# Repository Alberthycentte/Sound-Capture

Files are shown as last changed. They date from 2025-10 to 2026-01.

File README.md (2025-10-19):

# Sound Capture Device - User Manual By Albert Hycentte

## 📖 Table of Contents
1. [Introduction](#introduction)
2. [Hardware Overview](#hardware-overview)
3. [Getting Started](#getting-started)
4. [Operating Instructions](#operating-instructions)
5. [LED Status Indicators](#led-status-indicators)
6. [Technical Specifications](#technical-specifications)
7. [Firmware Upload Guide](#firmware-upload-guide)
8. [Troubleshooting](#troubleshooting)
9. [File Management](#file-management)
10. [Maintenance & Care](#maintenance--care)
11. [Advanced Configuration](#advanced-configuration)
12. [Safety Information](#safety-information)

---

## 🎤 Introduction

Welcome to the **Sound Capture Device**! This portable audio recorder allows you to:
- Record high-quality audio with a professional MEMS microphone
- Store recordings as standard WAV files on an SD card
- Play back recordings through a built-in amplifier and speaker
- Operate on battery power or USB for extended recording sessions

This device is perfect for voice memos, field recordings, interviews, lectures, music practice, or any situation where you need reliable audio capture.

---

## 🔧 Hardware Overview

### Main Components

| Component | Description | Location |
|---|---|---|
| **ESP32-S3** | Main processor | Center of PCB |
| **INMP441** | MEMS microphone | Bottom right of board |
| **MAX98357A** | Class D audio amplifier | Near speaker connector |
| **SD Card Slot** | Storage for recordings | Bottom left edge |
| **USB-C Port** | Power & programming | Top-left corner |
| **Battery Connector** | LiPo battery input | Left side |
| **Speaker Connector** | 4-8Ω speaker output | Left side |

### User Interface

#### Buttons (Bottom Edge)
```
[START]  [STOP]  [PLAY]  [BOOT]  [EN]
   │       │       │       │      │
   │       │       │       │      └─── Reset button
   │       │       │       └────────── Programming mode
   │       │       └────────────────── Play last recording
   │       └────────────────────────── Stop recording/playback
   └────────────────────────────────── Start recording
```

#### Status LED
- Located near buttons
- Provides visual feedback for all operations
- See [LED Status Indicators](#led-status-indicators) for details

---

## 🚀 Getting Started

### What You Need

**Essential:**
- ✅ Sound Capture Device
- ✅ MicroSD card (4GB - 32GB, FAT32 formatted)
- ✅ USB-C cable (for charging/programming)
- ✅ 4Ω or 8Ω speaker (2-3W rating)

**Optional:**
- 🔋 3.7V LiPo battery (1000-2000mAh recommended)
- 💻 Computer (for firmware updates)

### Initial Setup

#### Step 1: Insert SD Card
1. Power off the device
2. Insert microSD card into slot (gold contacts facing down)
3. Push until it clicks into place
4. **Important:** Card must be formatted as FAT32

#### Step 2: Connect Speaker
1. Locate the 2-pin speaker connector (SPK)
2. Connect speaker wires 
3. Use 4Ω or 8Ω speaker rated for 2-3W

#### Step 3: Power Connection

**Option A: USB Power**
- Connect USB-C cable to device
- Connect other end to USB power adapter or computer
- LED should blink twice on startup

**Option B: Battery Power**
- Connect 3.7V LiPo battery to J2 connector
- Observe polarity: RED (+), BLACK (-)
- Battery charges automatically when USB connected

#### Step 4: First Power-On
1. Connect power source
2. Wait for LED indicators:
   - 2 blinks = System starting
   - 3 blinks = Ready to use
3. Device is now ready for recording!

---

## 🎵 Operating Instructions

### Recording Audio

**Basic Recording:**
1. **Press START button** once
   - LED turns ON (solid)
   - Recording begins immediately
2. Speak or capture audio (max 60 seconds)
3. **Press STOP button** to finish
   - LED blinks 2 times
   - File saved to SD card

**Recording Tips:**
- Speak clearly at normal volume
- Avoid covering microphone hole
- Recording stops automatically after 60 seconds
- Each recording creates a new numbered file (`rec_1.wav`, `rec_2.wav`, etc.)

### Playing Back Audio

**Playing Last Recording:**
1. **Press PLAY button** once
   - LED blinks slowly (500ms intervals)
   - Last recorded file plays automatically
2. Audio plays through connected speaker
3. Playback stops automatically at end
   - Or press STOP button to interrupt

**Volume:**
- Volume is set by hardware (12dB gain)
- To adjust, modify GAIN_SLOT resistor (see Advanced Configuration)

### Stopping Operations

**Stop Recording or Playback:**
- **Press STOP button** at any time
- Current operation terminates immediately
- LED blinks to confirm stop
- File is saved (if recording) before stopping

---

## 💡 LED Status Indicators

Understanding the status LED helps you know what the device is doing:

| LED Pattern | Meaning | Action |
|---|---|---|
| **2 blinks on power-up** | System initializing | Wait 2-3 seconds |
| **3 quick blinks** | System ready | Device ready to use |
| **Solid ON** | Recording in progress | Recording audio |
| **Slow blink (500ms)** | Playing audio | Playback in progress |
| **2 blinks after stop** | File saved successfully | Recording complete |
| **3 blinks (play press)** | No recordings found | Record something first |
| **5 rapid blinks** | Error detected | Check SD card or connections |
| **Continuous rapid blinks** | Critical error | Check troubleshooting section |

---

## 📊 Technical Specifications

### Audio Performance
| Parameter | Specification |
|---|---|
| **Sample Rate** | 16 kHz (voice optimized) |
| **Bit Depth** | 16-bit |
| **Channels** | Mono |
| **Format** | WAV (PCM uncompressed) |
| **Frequency Response** | 50 Hz - 8 kHz |
| **Microphone SNR** | 61 dB |
| **Amplifier Output** | 3.2W @ 4Ω, 1.4W @ 8Ω |
| **THD+N** | < 1% @ 1kHz |

### Recording Capacity
| SD Card Size | Recording Time @ 16kHz |
|---|---|
| 4 GB | ~74 hours |
| 8 GB | ~148 hours |
| 16 GB | ~296 hours |
| 32 GB | ~592 hours |

**File Size:** Approximately 1.8 MB per minute of recording

### Power Specifications
| Mode | Current Draw | Battery Life (1000mAh) |
|---|---|---|
| **Idle** | 50 mA | ~20 hours |
| **Recording** | 150 mA | ~6.5 hours |
| **Playback (medium volume)** | 250 mA | ~4 hours |
| **Charging** | Up to 1000 mA | ~1.5 hours |

### Physical Specifications
- **Supply Voltage:** 5V USB or 3.7V LiPo battery
- **Operating Temperature:** 0°C to 50°C
- **Storage Temperature:** -20°C to 60°C
- **Humidity:** 10% to 85% non-condensing

---

## 💻 Firmware Upload Guide

### Prerequisites

**Software Requirements:**
- Visual Studio Code (recommended) or Arduino IDE
- PlatformIO extension (for VS Code)
- USB-C cable
- Computer (Windows/Mac/Linux)

### Installation Steps

#### 1. Install PlatformIO
```bash
# For VS Code users:
1. Open VS Code
2. Go to Extensions (Ctrl+Shift+X)
3. Search "PlatformIO IDE"
4. Click Install

# For command line:
pip install platformio
```

#### 2. Prepare Project
```
Create folder structure:
sound_capture/
├── platformio.ini
├── src/
│   └── main.cpp
└── include/
```

#### 3. Configure platformio.ini
```ini
[env:esp32-s3-devkitc-1]
platform = espressif32
board = esp32-s3-devkitc-1
framework = arduino
upload_speed = 921600
monitor_speed = 115200
```

#### 4. Upload Firmware

**Method A: Using VS Code**
1. Connect USB-C cable to device
2. Hold **BOOT button** (GPIO0)
3. Press and release **EN button**
4. Release **BOOT button**
5. Click "Upload" in PlatformIO toolbar
6. Wait for "SUCCESS" message

**Method B: Command Line**
```bash
cd sound_capture
pio run --target upload
```

#### 5. Verify Upload
```bash
# Open serial monitor
pio device monitor

# You should see:
=== Sound Capture Device ===
Initializing...
System ready!
```

### Firmware Updates
To update firmware in the future:
1. Download new firmware release
2. Follow upload steps above
3. Your recordings on SD card are preserved
4. Settings may need reconfiguration

---

## 🔧 Troubleshooting

### SD Card Issues

**Problem: "SD card mount failed"**
- ✅ Check card is fully inserted
- ✅ Format card as FAT32 (not exFAT or NTFS)
- ✅ Try a different SD card
- ✅ Clean SD card contacts
- ✅ Use card 32GB or smaller

**Problem: "Failed to create file"**
- ✅ Check SD card is not write-protected
- ✅ Ensure card has free space
- ✅ Verify card is formatted correctly
- ✅ Try creating `/recordings` folder manually

### Audio Issues

**Problem: No sound when recording**
- ✅ Check microphone is not blocked
- ✅ Speak louder or move closer (6-12 inches)
- ✅ Verify INMP441 power (3.3V)
- ✅ Check GPIO36, 37, 38 connections
- ✅ Test with different recording

**Problem: No sound during playback**
- ✅ Verify speaker is connected
- ✅ Check speaker impedance (4-8Ω)
- ✅ Ensure volume is adequate (hardware gain)
- ✅ Test speaker with another device
- ✅ Check GPIO3 is enabling amplifier

**Problem: Distorted or garbled audio**
- ✅ Reduce volume (change GAIN_SLOT)
- ✅ Don't speak too close to microphone
- ✅ Check for loose connections
- ✅ Verify sample rate (16kHz default)
- ✅ Try re-recording

### Power Issues

**Problem: Device won't turn on**
- ✅ Check USB cable is connected
- ✅ Verify battery is charged
- ✅ Try different USB power source
- ✅ Check battery polarity
- ✅ Press EN button to reset

**Problem: Battery not charging**
- ✅ Ensure USB is connected
- ✅ Check charge LED (D5) is ON
- ✅ Verify battery polarity
- ✅ Battery may be fully charged
- ✅ Wait 1-2 hours for full charge

### Button Issues

**Problem: Buttons not responding**
- ✅ Press firmly and release
- ✅ Wait 200ms between presses (debounce)
- ✅ Check device is in IDLE state
- ✅ Reset device (EN button)
- ✅ Verify GPIO connections

### Error LED Patterns

**5 rapid blinks:**
1. Check SD card is inserted
2. Verify card is formatted FAT32
3. Check all connections
4. Re-upload firmware
5. Check serial monitor for details

---

## 📁 File Management

### File Structure
```
SD Card Root/
└── recordings/
    ├── rec_1.wav
    ├── rec_2.wav
    ├── rec_3.wav
    └── ...
```

### Accessing Recordings

**On Computer:**
1. Remove SD card from device
2. Insert into computer SD card reader
3. Navigate to `recordings` folder
4. Copy WAV files to computer
5. Files can be played with any media player

**Supported Players:**
- Windows Media Player
- VLC Media Player
- QuickTime (Mac)
- Any WAV-compatible software

### File Naming
- Files automatically numbered: `rec_1.wav`, `rec_2.wav`, etc.
- Device remembers last number used
- Deleting files resets numbering to highest existing number + 1

### Storage Management

**Checking Free Space:**
- Serial monitor shows card size on startup
- Monitor: "SD Card Size: XXXXMB"

**Deleting Old Recordings:**
1. Remove SD card
2. Connect to computer
3. Delete unwanted files from `/recordings/` folder
4. Re-insert card into device
5. Next recording continues numbering

**Backup Recommendations:**
- Copy recordings to computer regularly
- Keep SD card backups
- Card can be reformatted if needed (loses all data)

---

## 🛠️ Maintenance & Care

### Daily Use
- Keep device clean and dry
- Avoid extreme temperatures
- Don't cover microphone hole
- Store in protective case when not in use

### SD Card Care
- Don't remove card while recording
- Keep contacts clean
- Avoid static discharge
- Replace every 2-3 years for reliability

### Battery Maintenance
- Charge fully before first use
- Don't fully discharge (keep above 20%)
- Charge at room temperature
- Replace if runtime significantly decreases
- Store at 40-60% charge if unused for months

### Speaker Care
- Don't exceed 3W rating
- Avoid water exposure
- Check connections periodically
- Replace if sound becomes distorted

### Cleaning
- Use dry, soft cloth for exterior
- Don't use liquids near electronics
- Compressed air can clean microphone hole
- Clean SD card slot with dry brush

### Firmware Updates
- Check for updates periodically
- Updates may add features or fix bugs
- Follow upload guide for updates
- Backup recordings before updating

---

## ⚙️ Advanced Configuration

### Changing Audio Quality

**Location:** Line 51-54 in `main.cpp`

```cpp
// Voice recording (default)
#define SAMPLE_RATE    16000
#define SAMPLE_BITS    16
#define I2S_CHANNELS   1

// Music quality
#define SAMPLE_RATE    44100  // CD quality
#define SAMPLE_BITS    16
#define I2S_CHANNELS   1      // or 2 for stereo

// Phone quality (smaller files)
#define SAMPLE_RATE    8000
```

**Effect on file size:**
- 8 kHz: ~0.9 MB/min
- 16 kHz: ~1.8 MB/min
- 44.1 kHz: ~5 MB/min

### Adjusting Recording Time

**Location:** Line 54 in `main.cpp`

```cpp
#define RECORD_TIME_MS  60000  // 60 seconds

// Change to:
#define RECORD_TIME_MS  120000  // 2 minutes
#define RECORD_TIME_MS  300000  // 5 minutes
```

### Volume Adjustment (Hardware)

**Current Configuration:**
- GAIN_SLOT connected to VSYST (5V) via 0Ω resistor (R23)
- This provides 12dB gain

**To Change Volume:**

| R23 Connection | Gain | Volume |
|---|---|---|
| GND | 9dB | Quieter |
| +3.3V | 12dB | Normal (current) |
| 100K to GND | 15dB | Louder |
| Open (DNP) | 18dB | Maximum |

**To modify:** Remove R23 and connect to desired voltage

### Custom File Naming

**Location:** Line 382 in `main.cpp`

```cpp
// Default naming
currentFileName = "/recordings/rec_" + String(recordingNumber) + ".wav";

// Custom naming examples:
currentFileName = "/recordings/audio_" + String(recordingNumber) + ".wav";
currentFileName = "/recordings/memo_" + String(millis()) + ".wav";
```

### Buffer Size Optimization

**Location:** Line 57 in `main.cpp`

```cpp
#define DMA_BUF_LEN    512  // Default

// For better quality, increase:
#define DMA_BUF_LEN    1024

// For lower latency, decrease:
#define DMA_BUF_LEN    256
```

**Note:** Larger buffers = smoother recording but more memory usage

---

## ⚠️ Safety Information

### Electrical Safety
- ⚡ Use only 5V USB power supply
- ⚡ Battery: 3.7V LiPo only (1000-2000mAh)
- ⚡ Observe battery polarity
- ⚡ Don't short-circuit battery terminals
- ⚡ Disconnect power during repairs

### Battery Safety
- 🔋 Use quality LiPo batteries with protection circuit
- 🔋 Don't puncture, crush, or disassemble battery
- 🔋 Keep away from heat/fire
- 🔋 Don't charge unattended
- 🔋 Dispose properly at recycling center

### Operating Precautions
- 💧 Not waterproof - avoid moisture
- 🌡️ Don't use in extreme temperatures
- 👂 Avoid excessive speaker volume near ears
- 🎤 Microphone not for medical/safety-critical use
- 📱 May interfere with sensitive equipment

### Environmental
- ♻️ Dispose of electronics responsibly
- ♻️ Recycle batteries at designated facilities
- ♻️ Keep away from children and pets
- ♻️ Follow local e-waste regulations

---

## 📞 Support & Resources

### Getting Help
1. Check this manual first
2. Review troubleshooting section
3. Check serial monitor for error messages
4. Verify all connections
5. Try known-good components (SD card, battery, etc.)

### Technical Support
- **Serial Monitor:** Connect USB and run `pio device monitor`
- **Debug Output:** Detailed startup and operation info
- **Error Messages:** Specific problem indicators

### Additional Resources
- **ESP32-S3 Datasheet:** Technical specifications
- **INMP441 Datasheet:** Microphone specifications
- **MAX98357A Datasheet:** Amplifier details
- **PlatformIO Documentation:** Development environment

---

## 📄 Specifications Summary

| Category | Details |
|---|---|
| **Processor** | ESP32-S3 Dual-core @ 240MHz |
| **Memory** | 512KB RAM, 16MB Flash |
| **Microphone** | INMP441 MEMS I2S |
| **Amplifier** | MAX98357A Class D, 3.2W |
| **Storage** | MicroSD up to 32GB |
| **Power** | USB-C 5V or 3.7V LiPo |
| **Battery** | 1000-2000mAh (4-6 hours) |
| **Audio Format** | 16kHz, 16-bit, Mono WAV |
| **Dimensions** | 60mm × 90mm (approximate) |
| **Weight** | ~50g (without battery) |

---

## 🎓 Quick Start Guide

**First-Time Users:**
1. ✅ Insert FAT32-formatted SD card
2. ✅ Connect 4-8Ω speaker
3. ✅ Connect USB-C power or battery
4. ✅ Wait for 3 LED blinks (ready)
5. ✅ Press START to record
6. ✅ Press STOP when done
7. ✅ Press PLAY to listen
8. ✅ Enjoy your recordings!

---

## 📜 Version History

**v1.0.0** (Current)
- Initial release
- Basic record/play/stop functionality
- WAV file format support
- Auto-numbering system
- Power management
- Status LED indicators

---

## 📝 Notes

- Device designed for voice recording applications
- Not intended for professional music production
- Recordings are mono (single channel)
- Maximum 60 seconds per recording (configurable)
- SD card required for operation
- Speaker required for playback
- Battery optional (can run from USB)

---

**Thank you for choosing the Sound Capture Device!**

For firmware updates, bug reports, or feature requests, please refer to the project repository or contact technical support.

**Happy Recording! 🎤🎵**

---

*Manual Version: 1.0.0*  
*Last Updated: 2025*  
*Compatible with Firmware: v1.0.0*

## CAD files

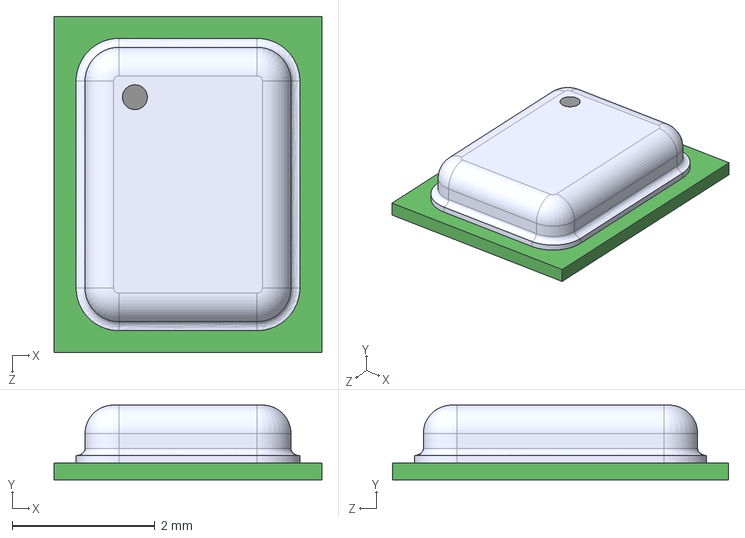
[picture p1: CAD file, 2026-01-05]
Sound Capture/INMP441 Mic/INMP441.step
3.76 x 1.05 x 4.72 mm

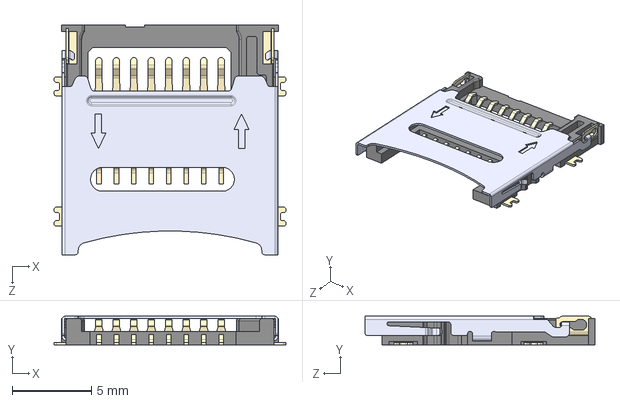
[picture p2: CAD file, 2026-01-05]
Sound Capture/SDcard/MEM2067-02-180-00-A_REVB.step
14.6 x 1.80 x 14.5 mm

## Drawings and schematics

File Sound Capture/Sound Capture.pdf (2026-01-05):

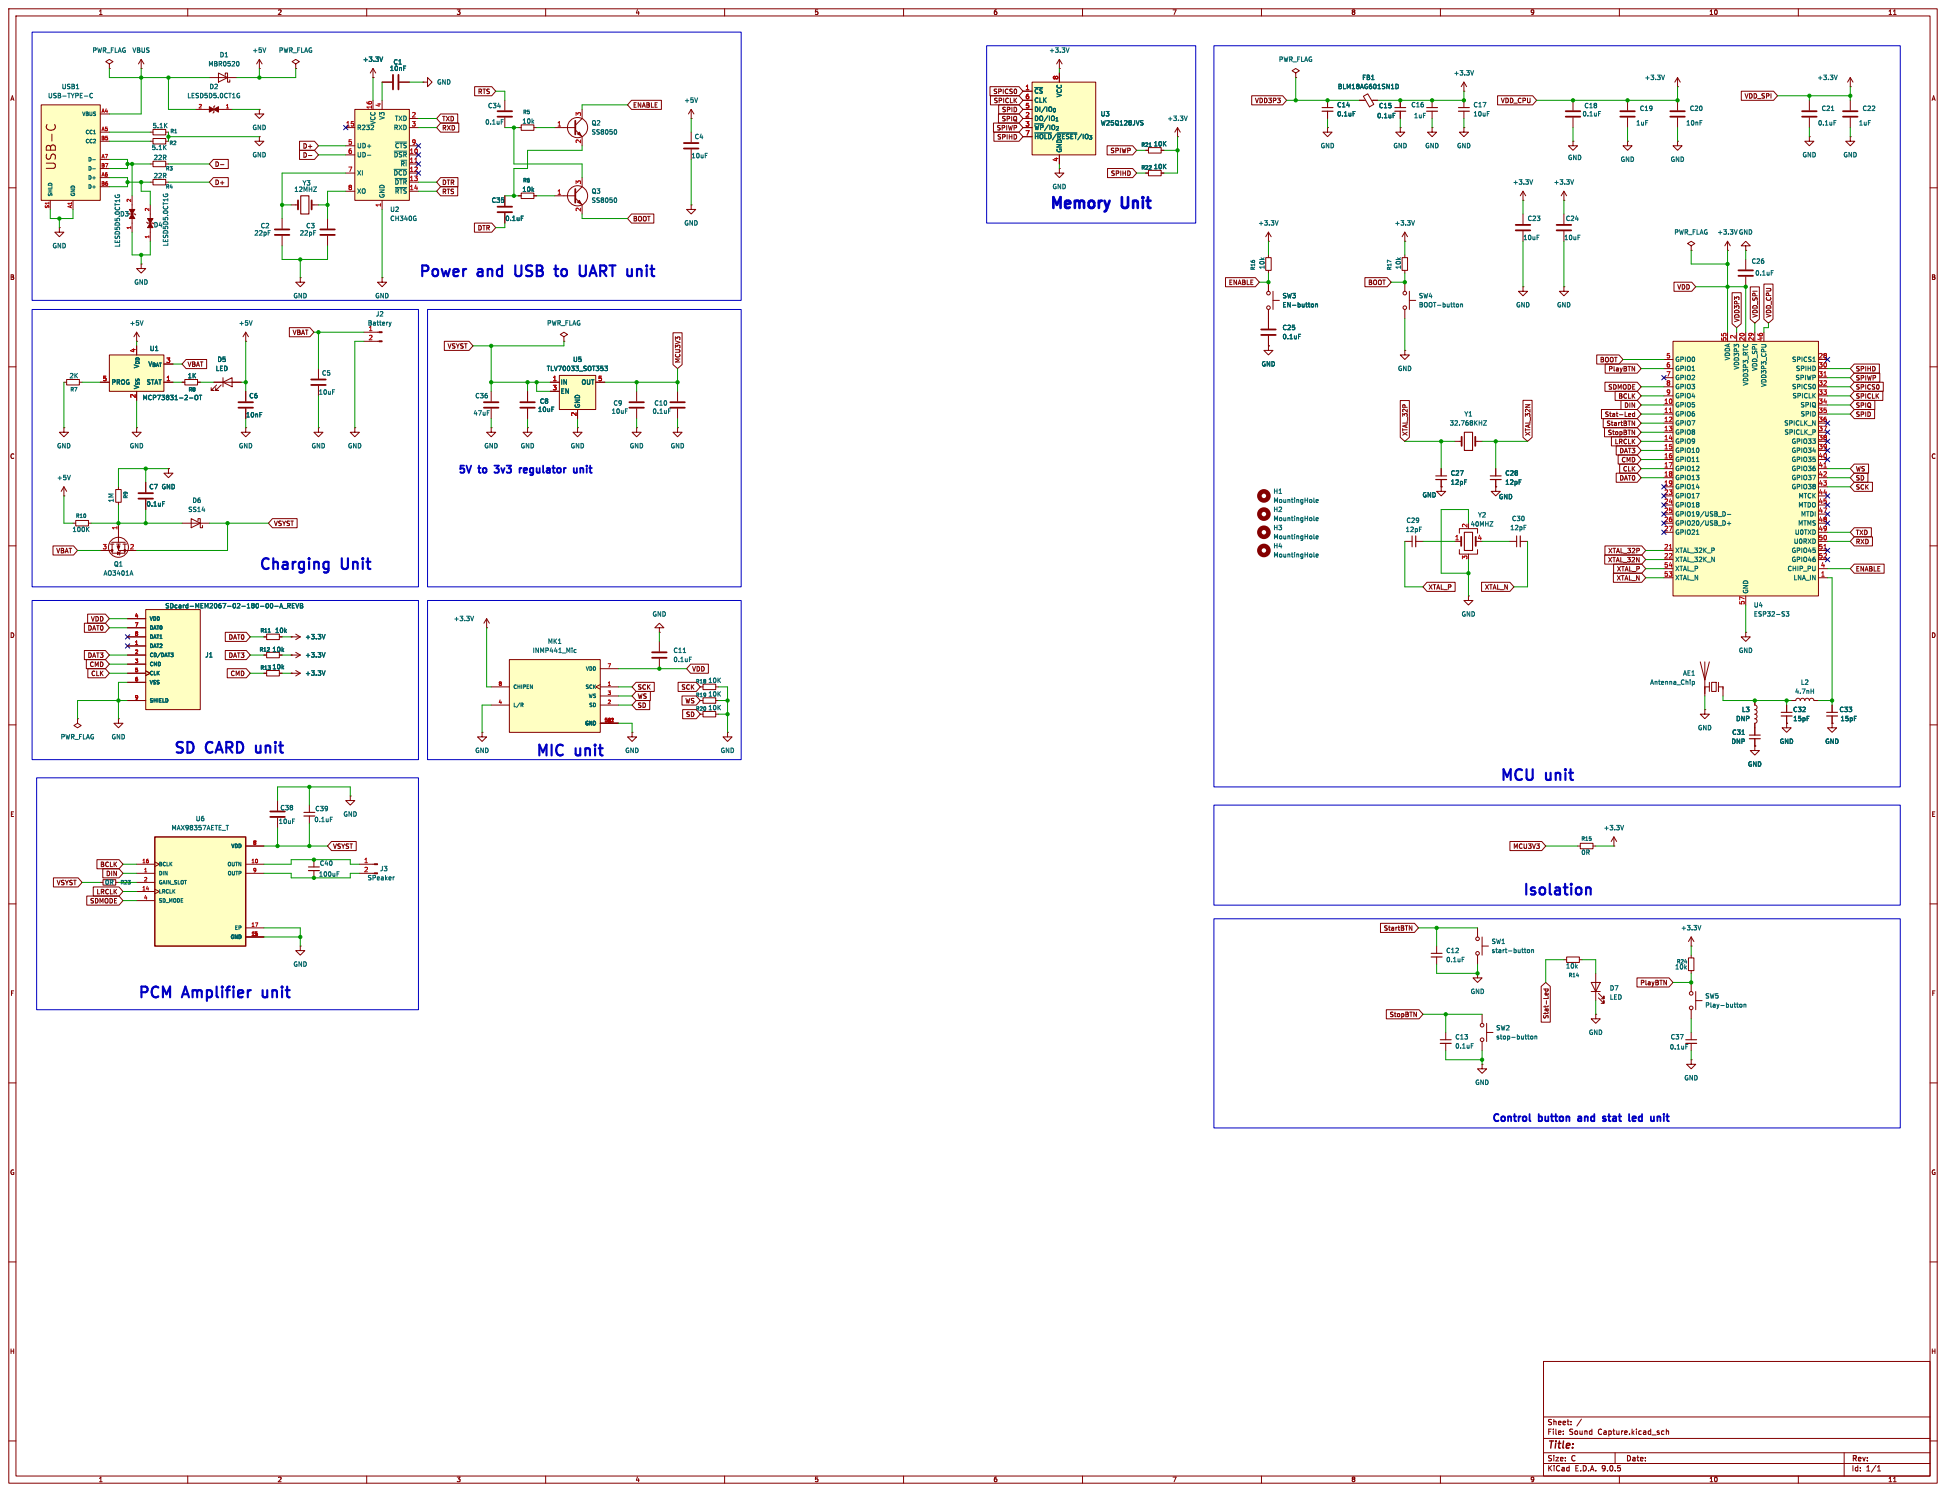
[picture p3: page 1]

VDD_SPI RTS PCM Amplifier unit

1 TXD 2 RXD 3 ~{CTS}9 ~{DSR} 10 ~{RI} 11 ~{DCD} 12 ~{DTR} 13 ~{RTS} 14 U2 CH340G

Power and USB to UART unit
10uFPWR_FLAG

Control button and stat led unit

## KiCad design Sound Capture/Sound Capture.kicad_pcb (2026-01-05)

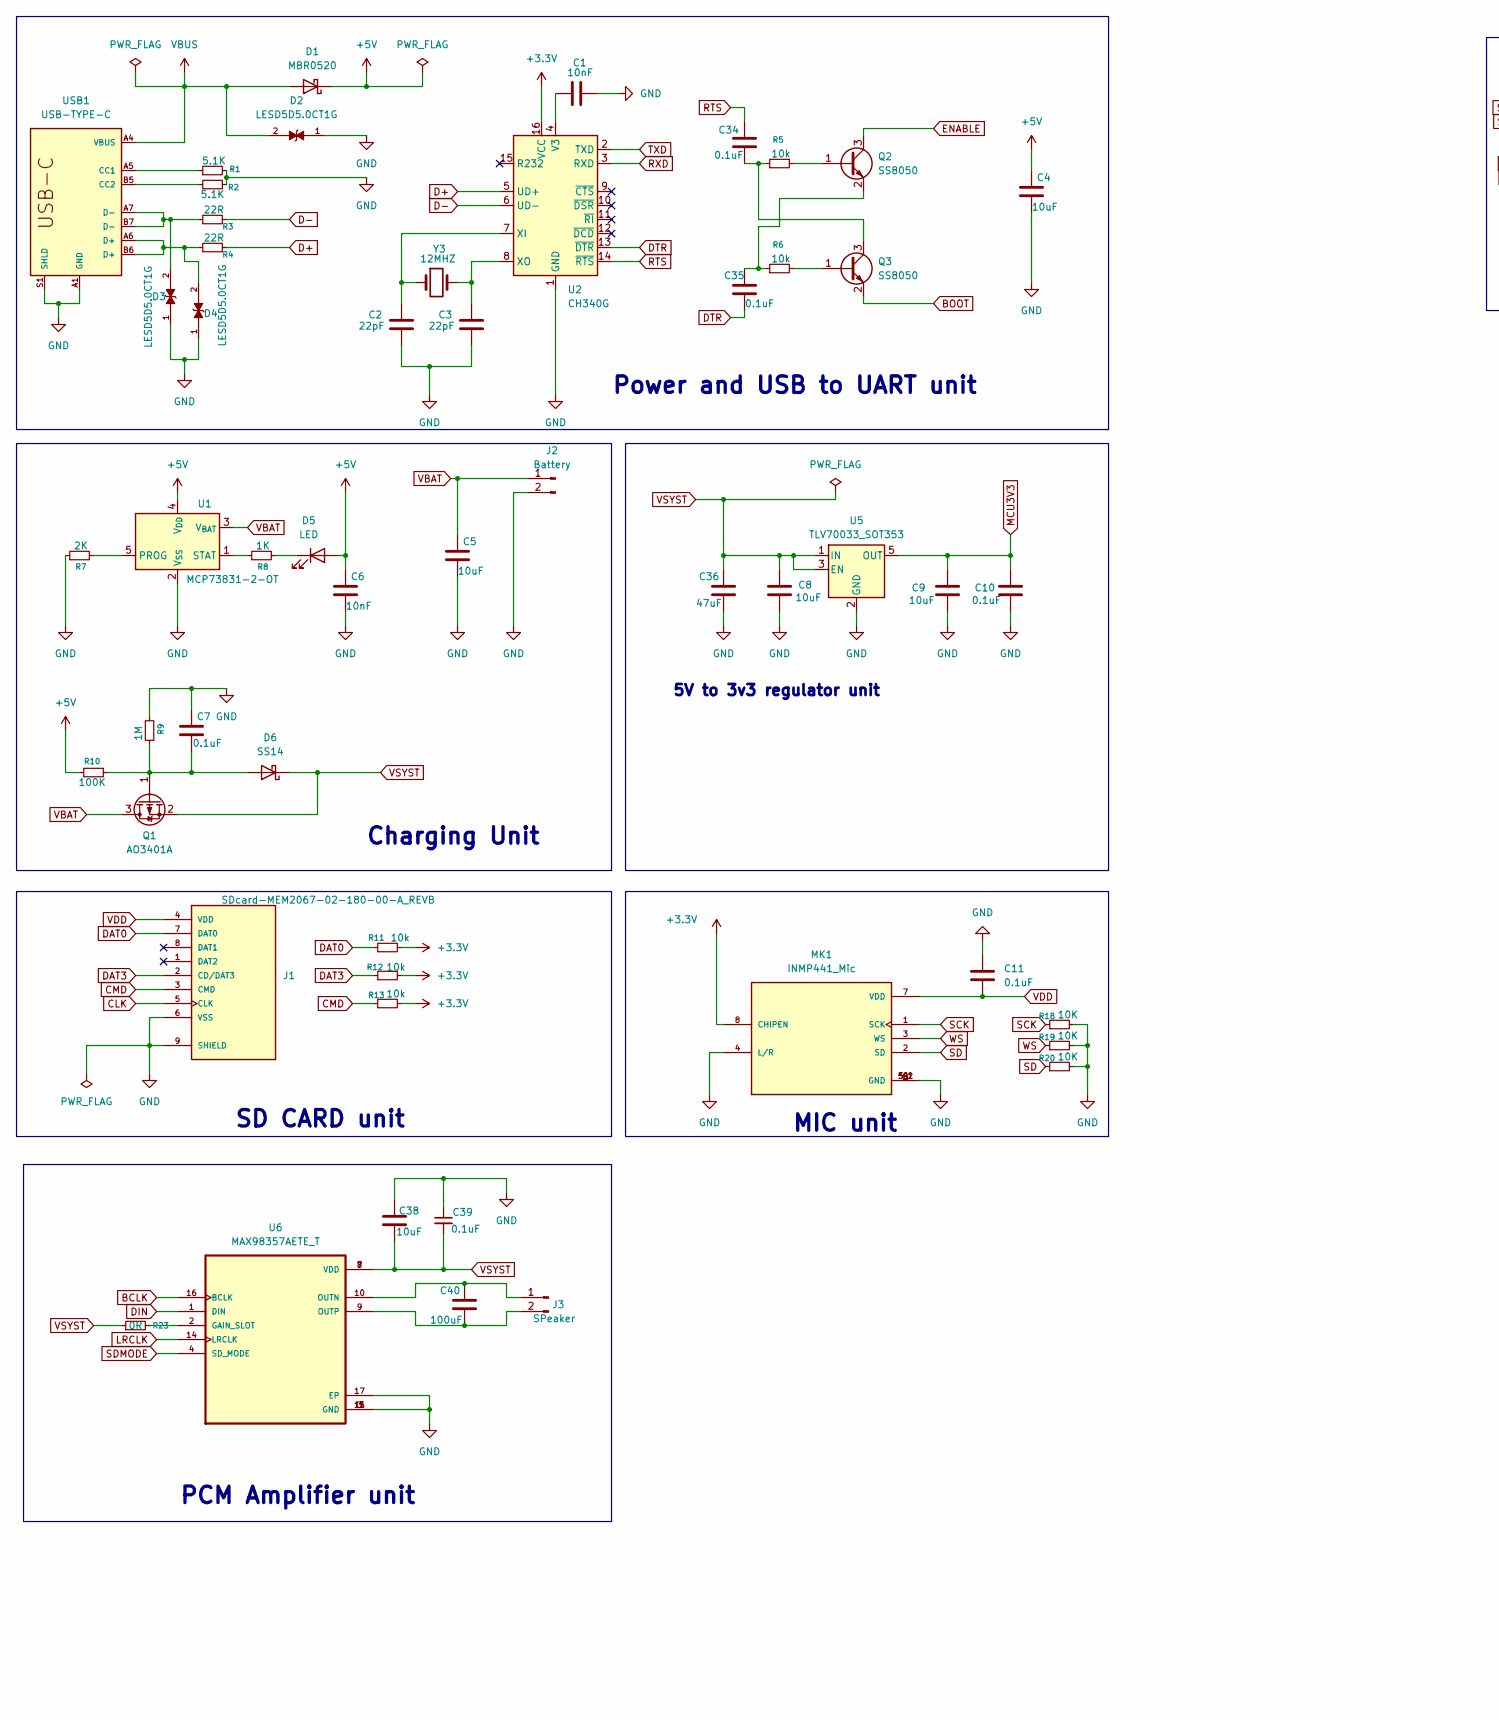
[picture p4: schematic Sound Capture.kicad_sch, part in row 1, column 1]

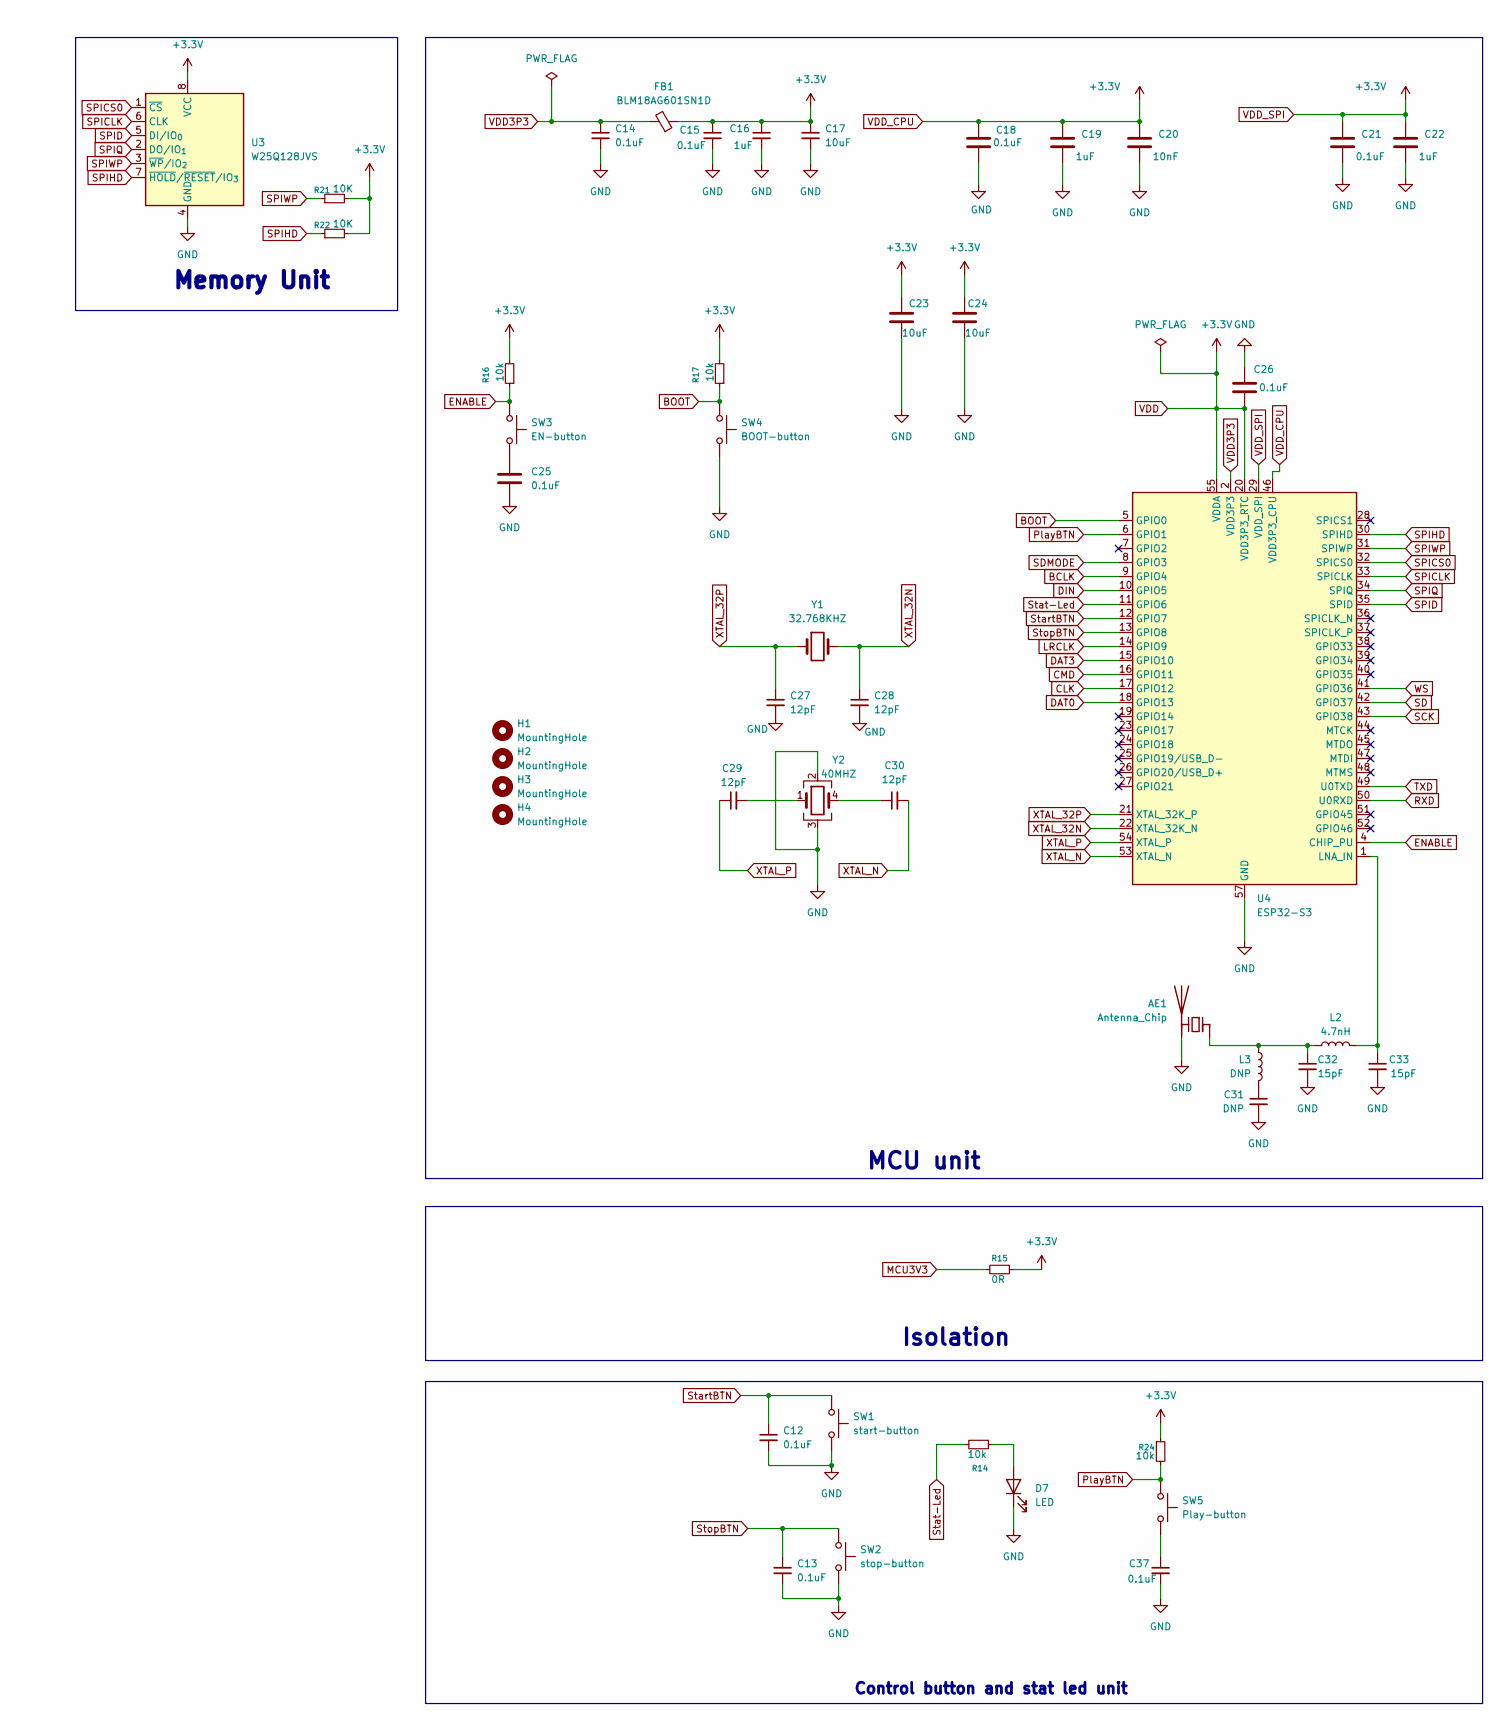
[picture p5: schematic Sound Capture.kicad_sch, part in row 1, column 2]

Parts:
AE1: Antenna_Chip; Texas_SWRA117D_2.4GHz_Left
C1, C6, C20: 10nF; C_0603_1608Metric
C2, C3: 22pF; C_0603_1608Metric
C4, C5, C8, C9, C23, C24, C38: 10uF; C_1206_3216Metric
C7, C10, C11, C18, C21, C25, C26, C34, C35: 0.1uF; C_0603_1608Metric
C12, C13, C14, C15, C37, C39: 0.1uF; C_0402_1005Metric
C16: 1uF; C_0402_1005Metric
C17: 10uF; C_0402_1005Metric
C19, C22: 1uF; C_0805_2012Metric
C27, C28, C29, C30: 12pF; C_0402_1005Metric
C31: DNP; C_0402_1005Metric
C32, C33: 15pF; C_0402_1005Metric
C36: 47uF; C_1210_3225Metric
C40: 100uF; C_1210_3225Metric
D1: MBR0520; D_SOD-123
D2, D3, D4: LESD5D5.0CT1G; TVS_LESD5D5.0CT1G; PARTREV O
D5, D7: LED; LED_0805_2012Metric
D6: SS14; D_SMA
FB1: BLM18AG601SN1D; BEADC1608X95N
H1, H2, H3, H4: MountingHole; MountingHole_2.5mm_Pad
J1: SDcard-MEM2067-02-180-00-A_REVB
J2: Battery; JST_XH_B2B-XH-A_1x02_P2.50mm_Vertical
J3: SPeaker; JST_XH_B2B-XH-A_1x02_P2.50mm_Vertical
L2: 4.7nH; L_0402_1005Metric
L3: DNP; L_0402_1005Metric
MK1: INMP441_Mic; MIC_INMP441
Q1: AO3401A; SOT-23
Q2, Q3: SS8050; SOT-23
R1, R2: 5.1K; R_0805_2012Metric
R3, R4: 22R; R_0805_2012Metric
R5, R6, R11, R12, R13, R14, R16, R17, R24: 10k; R_0603_1608Metric
R7: 2K; R_0603_1608Metric
R8: 1K; R_0603_1608Metric
R9: 1M; R_0603_1608Metric
R10: 100K; R_0603_1608Metric
R15: 0R; R_0603_1608Metric
R18, R19, R20, R21, R22: 10K; R_0603_1608Metric
R23: 0R; R_0805_2012Metric
SW1: start-button; SW_PUSH_6mm
SW2: stop-button; SW_PUSH_6mm
SW3: EN-button; SW_PUSH_6mm_H5mm
SW4: BOOT-button; SW_PUSH_6mm_H5mm
SW5: Play-button; SW_PUSH_6mm
U1: MCP73831-2-OT; SOT-23-5
U2: CH340G; SOIC-16_3.9x9.9mm_P1.27mm
U3: W25Q128JVS; SOIC-8_5.3x5.3mm_P1.27mm
U4: ESP32-S3; QFN-56-1EP_7x7mm_P0.4mm_EP4x4mm
U5: TLV70033_SOT353; SOT-353_SC-70-5
U6: MAX98357AETE_T; MAX98357AETE+T -QFN50P300X300X80-17N
USB1: USB-TYPE-C; USBC.USB4110-GF-A
Y1: 32.768KHZ; Crystal_SMD_3215-2Pin_3.2x1.5mm
Y2: 40MHZ; Crystal_SMD_2520-4Pin_2.5x2.0mm
Y3: 12MHZ; XTAL_ABLS2-12.000MHZ-D4Y-T

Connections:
+5V: C4.1, C6.1, D1.1 (K), D5.2 (A), R10.2, U1.4 (V_{DD})
BCLK: U4.9 (GPIO4), U6.16 (BCLK)
BOOT: Q3.2 (E), R17.1, SW4.1, U4.5 (GPIO0)
CLK: J1.5 (CLK), U4.17 (GPIO12)
CMD: J1.3 (CMD), R13.1, U4.16 (GPIO11)
D+: R4.2, U2.5 (UD+)
D-: R3.2, U2.6 (UD-)
DAT0: J1.7 (DAT0), R11.1, U4.18 (GPIO13)
DAT3: J1.2 (CD/DAT3), R12.1, U4.15 (GPIO10)
DIN: U4.10 (GPIO5), U6.1 (DIN)
DTR: C35.1, U2.13 (~DTR)
ENABLE: Q2.3 (C), R16.1, SW3.1, U4.4 (CHIP_PU)
GND: AE1.2 (PCB_Trace), C1.2, C2.1, C3.1, C4.2, C5.2, C6.2, C7.1, C8.1, C9.1, C10.1, C11.1, C12.2, C13.2, C14.2, C15.2, C16.2, C17.2, C18.1, C19.1, C20.1, C21.1, C22.1, C23.2, C24.2, C25.2, C26.2, C27.2, C28.2, C31.2, C32.2, C33.2, C36.1, C37.2, C38.1, C39.1, D2.1, D3.1, D4.1, D7.1 (K), J1.6 (VSS), J1.9 (SHIELD), J2.2, MK1.4 (L/R), MK1.5_1 (GND), MK1.5_2 (GND), MK1.6 (GND), MK1.9 (GND), R1.2, R2.2, R7.1, R9.2, R18.2, R19.2, R20.2, SW1.2, SW2.2, SW4.2, U1.2 (V_{SS}), U2.1 (GND), U3.4 (GND), U4.57 (GND), U5.2 (GND), U6.3 (GND), U6.11 (GND), U6.15 (GND), U6.17 (EP), USB1.A1 (GND), USB1.S1 (SHLD), Y2.2, Y2.3
LRCLK: U4.14 (GPIO9), U6.14 (LRCLK)
MCU3V3: C9.2, C10.2, R15.2, U5.5 (OUT)
unnamed: AE1.1 (FEED), C32.1, L2.2, L3.2
unnamed: C25.1, SW3.2
unnamed: C29.2, Y2.1
unnamed: C30.1, Y2.4
unnamed: C31.1, L3.1
unnamed: C37.1, SW5.2
unnamed: D3.2, R3.1, USB1.A7 (D-), USB1.B7 (D-)
unnamed: D4.2, R4.1, USB1.A6 (D+), USB1.B6 (D+)
unnamed: D5.1 (K), R8.2
unnamed: C7.2, D6.2 (A), Q1.1 (G), R9.1, R10.1
unnamed: D7.2 (A), R14.1
unnamed: C40.2, J3.1, U6.10 (OUTN)
unnamed: C40.1, J3.2, U6.9 (OUTP)
unnamed: Q2.1 (B), R5.2
unnamed: C35.2, Q2.2 (E), R6.1
unnamed: Q3.1 (B), R6.2
unnamed: C34.1, Q3.3 (C), R5.1
unnamed: R7.2, U1.5 (PROG)
unnamed: R8.1, U1.1 (STAT)
unnamed: C1.1, U2.4 (V3)
unnamed: C2.2, U2.7 (XI), Y3.1
unnamed: C3.2, U2.8 (XO), Y3.2
unnamed: C33.1, L2.1, U4.1 (LNA_IN)
unnamed: R23.2, U6.2 (GAIN_SLOT)
unnamed: R1.1, USB1.A5 (CC1)
unnamed: R2.1, USB1.B5 (CC2)
PlayBTN: R24.2, SW5.1, U4.6 (GPIO1)
RTS: C34.2, U2.14 (~RTS)
RXD: U2.3 (RXD), U4.50 (U0RXD)
SCK: MK1.1 (SCK), R18.1, U4.43 (GPIO38)
SD: MK1.2 (SD), R20.1, U4.42 (GPIO37)
SDMODE: U4.8 (GPIO3), U6.4 (SD_MODE)
SPICLK: U3.6 (CLK), U4.33 (SPICLK)
SPICS0: U3.1 (~CS), U4.32 (SPICS0)
SPID: U3.5 (DI/IO_{0}), U4.35 (SPID)
SPIHD: R22.1, U3.7 (~HOLD/~RESET/IO_{3}), U4.30 (SPIHD)
SPIQ: U3.2 (DO/IO_{1}), U4.34 (SPIQ)
SPIWP: R21.1, U3.3 (~WP/IO_{2}), U4.31 (SPIWP)
StartBTN: C12.1, SW1.1, U4.12 (GPIO7)
Stat-Led: R14.2, U4.11 (GPIO6)
StopBTN: C13.1, SW2.1, U4.13 (GPIO8)
TXD: U2.2 (TXD), U4.49 (U0TXD)
VBAT: C5.1, J2.1, Q1.3 (D), U1.3 (V_{BAT})
VBUS: D1.2 (A), D2.2, USB1.A4 (VBUS)
VDD: C11.2, C15.1, C16.1, C17.1, C18.2, C19.2, C20.2, C21.2, C22.2, C23.1, C24.1, C26.1, FB1.1, J1.4 (VDD), MK1.7 (VDD), MK1.8 (CHIPEN), R11.2, R12.2, R13.2, R15.1, R16.2, R17.2, R21.2, R22.2, R24.1, U2.16 (VCC), U3.8 (VCC), U4.20 (VDD3P3_RTC), U4.29 (VDD_SPI), U4.46 (VDD3P3_CPU), U4.55 (VDDA), U4.56 (VDDA)
VDD3P3: C14.1, FB1.2, U4.2 (VDD3P3), U4.3 (VDD3P3)
VSYST: C8.2, C36.2, C38.2, C39.2, D6.1 (K), Q1.2 (S), R23.1, U5.1 (IN), U5.3 (EN), U6.7 (VDD), U6.8 (VDD)
WS: MK1.3 (WS), R19.1, U4.41 (GPIO36)
XTAL_32N: C28.1, U4.22 (XTAL_32K_N), Y1.2
XTAL_32P: C27.1, U4.21 (XTAL_32K_P), Y1.1
XTAL_N: C30.2, U4.53 (XTAL_N)
XTAL_P: C29.1, U4.54 (XTAL_P)

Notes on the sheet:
MCU unit
PCM Amplifier unit
Power and USB to UART unit
SD CARD unit
Isolation
Control button and stat led unit
MIC unit
5V to 3v3 regulator unit
Charging Unit
Memory Unit

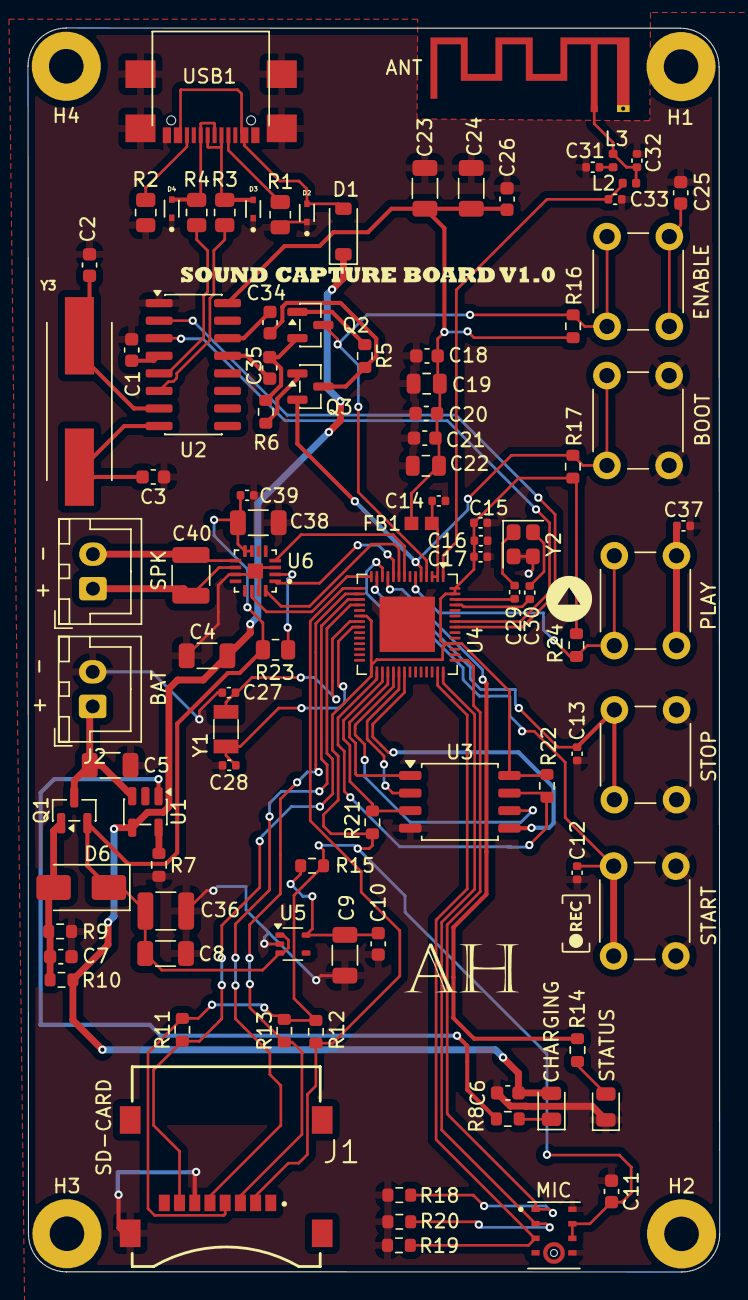
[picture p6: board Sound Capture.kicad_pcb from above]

Board: 2 copper layers, 50.0 x 90.0 mm, 101 parts (0 on the bottom side), 67 nets.

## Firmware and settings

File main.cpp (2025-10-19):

/*
 * Sound Capture Device - Designed By Albert Hycentte
 * ESP32-S3 with INMP441 Microphone and MAX98357A Amplifier
 * Features: Record, Play, Stop with SD card storage
 * 
 * Hardware Configuration:
 * - Microphone: INMP441 (I2S Input on GPIO36, 37, 38)
 * - Amplifier: MAX98357A (I2S Output on GPIO4, 5, 9)
 * - SD Card: SPI mode (GPIO10, 11, 12, 13)
 * - Buttons: Start (GPIO7), Stop (GPIO8), Play (GPIO1)
 * - Status LED: GPIO6
 * - Amplifier Enable: GPIO3
 */

#include <Arduino.h>
#include <driver/i2s.h>
#include <SD.h>
#include <SPI.h>

// ===== GPIO Pin Definitions =====
// I2S Input (INMP441 Microphone)
#define I2S_MIC_WS          36
#define I2S_MIC_SD          37
#define I2S_MIC_SCK         38

// I2S Output (MAX98357A Amplifier)
#define I2S_SPK_BCLK        4
#define I2S_SPK_DIN         5
#define I2S_SPK_LRCLK       9
#define I2S_SPK_SD_MODE     3  // Amplifier enable/disable

// SD Card (SPI Mode)
#define SD_CS               10
#define SD_CMD              11  // MOSI
#define SD_CLK              12  // SCK
#define SD_DAT0             13  // MISO

// User Interface
#define BTN_START           7
#define BTN_STOP            8
#define BTN_PLAY            1
#define LED_STATUS          6

// ===== Audio Configuration =====
#define SAMPLE_RATE         16000  // 16kHz for voice recording
#define SAMPLE_BITS         16
#define I2S_CHANNELS        1      // Mono
#define DMA_BUF_COUNT       8
#define DMA_BUF_LEN         512
#define RECORD_TIME_MS      60000  // Max 60 seconds per recording
#define WAV_HEADER_SIZE     44

// ===== I2S Port Definitions =====
#define I2S_MIC_PORT        I2S_NUM_0  // Input from microphone
#define I2S_SPK_PORT        I2S_NUM_1  // Output to speaker

// ===== Device States =====
enum DeviceState {
  STATE_IDLE,
  STATE_RECORDING,
  STATE_PLAYING,
  STATE_ERROR
};

// ===== Global Variables =====
DeviceState currentState = STATE_IDLE;
File audioFile;
String currentFileName = "";
uint32_t recordingNumber = 1;
unsigned long recordStartTime = 0;
bool sdCardReady = false;

// Audio buffers
int16_t* audioBuffer = nullptr;
const size_t BUFFER_SIZE = DMA_BUF_LEN * 4;

// ===== WAV File Header Structure =====
struct WAVHeader {
  // RIFF Chunk
  char riff[4] = {'R', 'I', 'F', 'F'};
  uint32_t fileSize;
  char wave[4] = {'W', 'A', 'V', 'E'};
  
  // Format Chunk
  char fmt[4] = {'f', 'm', 't', ' '};
  uint32_t fmtSize = 16;
  uint16_t audioFormat = 1;  // PCM
  uint16_t numChannels = I2S_CHANNELS;
  uint32_t sampleRate = SAMPLE_RATE;
  uint32_t byteRate;
  uint16_t blockAlign;
  uint16_t bitsPerSample = SAMPLE_BITS;
  
  // Data Chunk
  char data[4] = {'d', 'a', 't', 'a'};
  uint32_t dataSize;
};

// ===== Function Prototypes =====
void setupI2SMicrophone();
void setupI2SSpeaker();
void shutdownI2SSpeaker();
void setupSDCard();
void setupButtons();
void setupLED();
void ledBlink(int times, int delayMs);
void ledOn();
void ledOff();
void startRecording();
void stopRecording();
void startPlayback();
void stopPlayback();
void recordAudioTask();
void playAudioTask();
void writeWAVHeader(File& file, uint32_t dataSize);
void handleButtons();
void printError(const char* message);

// ===== Setup Function =====
void setup() {
  Serial.begin(115200);
  delay(1000);
  
  Serial.println("\n=== Sound Capture Device ===");
  Serial.println("Initializing...");
  
  // Initialize LED first for status indication
  setupLED();
  ledBlink(2, 200);  // Startup indication
  
  // Allocate audio buffer
  audioBuffer = (int16_t*)malloc(BUFFER_SIZE * sizeof(int16_t));
  if (!audioBuffer) {
    printError("Failed to allocate audio buffer");
    currentState = STATE_ERROR;
    return;
  }
  
  // Initialize peripherals
  setupButtons();
  setupSDCard();
  setupI2SMicrophone();
  
  // Keep speaker amplifier off initially (save power)
  pinMode(I2S_SPK_SD_MODE, OUTPUT);
  digitalWrite(I2S_SPK_SD_MODE, LOW);
  
  if (sdCardReady) {
    Serial.println("System ready!");
    ledBlink(3, 100);  // Ready indication
    currentState = STATE_IDLE;
  } else {
    printError("SD Card not ready");
    currentState = STATE_ERROR;
  }
}

// ===== Main Loop =====
void loop() {
  handleButtons();
  
  switch (currentState) {
    case STATE_IDLE:
      ledOff();
      delay(50);
      break;
      
    case STATE_RECORDING:
      ledOn();
      recordAudioTask();
      
      // Auto-stop after max recording time
      if (millis() - recordStartTime > RECORD_TIME_MS) {
        Serial.println("Max recording time reached");
        stopRecording();
      }
      break;
      
    case STATE_PLAYING:
      ledBlink(1, 500);  // Blink while playing
      playAudioTask();
      break;
      
    case STATE_ERROR:
      ledBlink(5, 100);  // Rapid blink for error
      delay(2000);
      break;
  }
}

// ===== I2S Microphone Setup =====
void setupI2SMicrophone() {
  Serial.println("Configuring I2S microphone...");
  
  i2s_config_t i2s_config = {
    .mode = (i2s_mode_t)(I2S_MODE_MASTER | I2S_MODE_RX),
    .sample_rate = SAMPLE_RATE,
    .bits_per_sample = I2S_BITS_PER_SAMPLE_16BIT,
    .channel_format = I2S_CHANNEL_FMT_ONLY_LEFT,
    .communication_format = I2S_COMM_FORMAT_STAND_I2S,
    .intr_alloc_flags = ESP_INTR_FLAG_LEVEL1,
    .dma_buf_count = DMA_BUF_COUNT,
    .dma_buf_len = DMA_BUF_LEN,
    .use_apll = false,
    .tx_desc_auto_clear = false,
    .fixed_mclk = 0
  };
  
  i2s_pin_config_t pin_config = {
    .bck_io_num = I2S_MIC_SCK,
    .ws_io_num = I2S_MIC_WS,
    .data_out_num = I2S_PIN_NO_CHANGE,
    .data_in_num = I2S_MIC_SD
  };
  
  esp_err_t err = i2s_driver_install(I2S_MIC_PORT, &i2s_config, 0, NULL);
  if (err != ESP_OK) {
    printError("Failed to install I2S mic driver");
    return;
  }
  
  err = i2s_set_pin(I2S_MIC_PORT, &pin_config);
  if (err != ESP_OK) {
    printError("Failed to set I2S mic pins");
    return;
  }
  
  Serial.println("I2S microphone ready");
}

// ===== I2S Speaker Setup =====
void setupI2SSpeaker() {
  Serial.println("Configuring I2S speaker...");
  
  // Enable amplifier
  digitalWrite(I2S_SPK_SD_MODE, HIGH);
  delay(50);  // Give amplifier time to power up
  
  i2s_config_t i2s_config = {
    .mode = (i2s_mode_t)(I2S_MODE_MASTER | I2S_MODE_TX),
    .sample_rate = SAMPLE_RATE,
    .bits_per_sample = I2S_BITS_PER_SAMPLE_16BIT,
    .channel_format = I2S_CHANNEL_FMT_ONLY_LEFT,
    .communication_format = I2S_COMM_FORMAT_STAND_I2S,
    .intr_alloc_flags = ESP_INTR_FLAG_LEVEL1,
    .dma_buf_count = DMA_BUF_COUNT,
    .dma_buf_len = DMA_BUF_LEN,
    .use_apll = false,
    .tx_desc_auto_clear = true,
    .fixed_mclk = 0
  };
  
  i2s_pin_config_t pin_config = {
    .bck_io_num = I2S_SPK_BCLK,
    .ws_io_num = I2S_SPK_LRCLK,
    .data_out_num = I2S_SPK_DIN,
    .data_in_num = I2S_PIN_NO_CHANGE
  };
  
  esp_err_t err = i2s_driver_install(I2S_SPK_PORT, &i2s_config, 0, NULL);
  if (err != ESP_OK) {
    printError("Failed to install I2S speaker driver");
    return;
  }
  
  err = i2s_set_pin(I2S_SPK_PORT, &pin_config);
  if (err != ESP_OK) {
    printError("Failed to set I2S speaker pins");
    return;
  }
  
  // Set volume by clearing any previous data
  i2s_zero_dma_buffer(I2S_SPK_PORT);
  
  Serial.println("I2S speaker ready");
}

// ===== Shutdown Speaker =====
void shutdownI2SSpeaker() {
  i2s_driver_uninstall(I2S_SPK_PORT);
  digitalWrite(I2S_SPK_SD_MODE, LOW);  // Disable amplifier (save power)
  Serial.println("Speaker shut down");
}

// ===== SD Card Setup =====
void setupSDCard() {
  Serial.println("Initializing SD card...");
  
  SPI.begin(SD_CLK, SD_DAT0, SD_CMD, SD_CS);
  
  if (!SD.begin(SD_CS, SPI, 25000000)) {
    printError("SD card mount failed");
    sdCardReady = false;
    return;
  }
  
  uint8_t cardType = SD.cardType();
  if (cardType == CARD_NONE) {
    printError("No SD card attached");
    sdCardReady = false;
    return;
  }
  
  Serial.print("SD Card Type: ");
  if (cardType == CARD_MMC) Serial.println("MMC");
  else if (cardType == CARD_SD) Serial.println("SDSC");
  else if (cardType == CARD_SDHC) Serial.println("SDHC");
  else Serial.println("UNKNOWN");
  
  uint64_t cardSize = SD.cardSize() / (1024 * 1024);
  Serial.printf("SD Card Size: %lluMB\n", cardSize);
  
  // Create recordings directory
  if (!SD.exists("/recordings")) {
    SD.mkdir("/recordings");
  }
  
  // Find next recording number
  File root = SD.open("/recordings");
  while (File file = root.openNextFile()) {
    String name = file.name();
    if (name.startsWith("rec_") && name.endsWith(".wav")) {
      int num = name.substring(4, name.length() - 4).toInt();
      if (num >= recordingNumber) {
        recordingNumber = num + 1;
      }
    }
    file.close();
  }
  root.close();
  
  sdCardReady = true;
  Serial.println("SD card ready");
}

// ===== Button Setup =====
void setupButtons() {
  pinMode(BTN_START, INPUT_PULLUP);
  pinMode(BTN_STOP, INPUT_PULLUP);
  pinMode(BTN_PLAY, INPUT_PULLUP);
  Serial.println("Buttons configured");
}

// ===== LED Functions =====
void setupLED() {
  pinMode(LED_STATUS, OUTPUT);
  digitalWrite(LED_STATUS, LOW);
}

void ledOn() {
  digitalWrite(LED_STATUS, HIGH);
}

void ledOff() {
  digitalWrite(LED_STATUS, LOW);
}

void ledBlink(int times, int delayMs) {
  for (int i = 0; i < times; i++) {
    digitalWrite(LED_STATUS, HIGH);
    delay(delayMs);
    digitalWrite(LED_STATUS, LOW);
    delay(delayMs);
  }
}

// ===== Start Recording =====
void startRecording() {
  if (!sdCardReady) {
    printError("SD card not ready");
    return;
  }
  
  if (currentState == STATE_RECORDING) {
    Serial.println("Already recording");
    return;
  }
  
  // Generate filename
  currentFileName = "/recordings/rec_" + String(recordingNumber) + ".wav";
  Serial.println("Starting recording: " + currentFileName);
  
  // Create and open file
  audioFile = SD.open(currentFileName, FILE_WRITE);
  if (!audioFile) {
    printError("Failed to create file");
    return;
  }
  
  // Write placeholder WAV header (will update later)
  writeWAVHeader(audioFile, 0);
  
  // Clear I2S buffer
  i2s_zero_dma_buffer(I2S_MIC_PORT);
  
  currentState = STATE_RECORDING;
  recordStartTime = millis();
  recordingNumber++;
  
  Serial.println("Recording started");
  ledOn();
}

// ===== Stop Recording =====
void stopRecording() {
  if (currentState != STATE_RECORDING) {
    return;
  }
  
  Serial.println("Stopping recording...");
  
  // Get file size and update WAV header
  uint32_t fileSize = audioFile.size();
  uint32_t dataSize = fileSize - WAV_HEADER_SIZE;
  
  audioFile.seek(0);
  writeWAVHeader(audioFile, dataSize);
  audioFile.close();
  
  currentState = STATE_IDLE;
  
  Serial.printf("Recording saved: %s (%.2f seconds)\n", 
                currentFileName.c_str(), 
                (float)dataSize / (SAMPLE_RATE * 2));
  
  ledBlink(2, 200);
}

// ===== Start Playback =====
void startPlayback() {
  if (!sdCardReady) {
    printError("SD card not ready");
    return;
  }
  
  if (currentState == STATE_PLAYING) {
    Serial.println("Already playing");
    return;
  }
  
  // Find last recording
  String lastFile = "";
  int lastNum = 0;
  File root = SD.open("/recordings");
  while (File file = root.openNextFile()) {
    String name = file.name();
    if (name.startsWith("rec_") && name.endsWith(".wav")) {
      int num = name.substring(4, name.length() - 4).toInt();
      if (num > lastNum) {
        lastNum = num;
        lastFile = "/recordings/" + name;
      }
    }
    file.close();
  }
  root.close();
  
  if (lastFile == "") {
    printError("No recordings found");
    ledBlink(3, 100);
    return;
  }
  
  currentFileName = lastFile;
  Serial.println("Playing: " + currentFileName);
  
  // Open file
  audioFile = SD.open(currentFileName, FILE_READ);
  if (!audioFile) {
    printError("Failed to open file");
    return;
  }
  
  // Skip WAV header
  audioFile.seek(WAV_HEADER_SIZE);
  
  // Setup speaker
  setupI2SSpeaker();
  
  currentState = STATE_PLAYING;
  Serial.println("Playback started");
}

// ===== Stop Playback =====
void stopPlayback() {
  if (currentState != STATE_PLAYING) {
    return;
  }
  
  Serial.println("Stopping playback...");
  
  audioFile.close();
  shutdownI2SSpeaker();
  
  currentState = STATE_IDLE;
  Serial.println("Playback stopped");
  ledOff();
}

// ===== Record Audio Task =====
void recordAudioTask() {
  size_t bytesRead = 0;
  
  // Read from microphone
  esp_err_t result = i2s_read(I2S_MIC_PORT, audioBuffer, 
                              BUFFER_SIZE * sizeof(int16_t), 
                              &bytesRead, portMAX_DELAY);
  
  if (result == ESP_OK && bytesRead > 0) {
    // Write to SD card
    size_t bytesWritten = audioFile.write((uint8_t*)audioBuffer, bytesRead);
    
    if (bytesWritten != bytesRead) {
      printError("Write error");
      stopRecording();
    }
  }
}

// ===== Play Audio Task =====
void playAudioTask() {
  size_t bytesRead = audioFile.read((uint8_t*)audioBuffer, BUFFER_SIZE * sizeof(int16_t));
  
  if (bytesRead > 0) {
    size_t bytesWritten = 0;
    i2s_write(I2S_SPK_PORT, audioBuffer, bytesRead, &bytesWritten, portMAX_DELAY);
  } else {
    // End of file
    Serial.println("Playback finished");
    stopPlayback();
  }
}

// ===== Write WAV Header =====
void writeWAVHeader(File& file, uint32_t dataSize) {
  WAVHeader header;
  
  header.byteRate = SAMPLE_RATE * I2S_CHANNELS * (SAMPLE_BITS / 8);
  header.blockAlign = I2S_CHANNELS * (SAMPLE_BITS / 8);
  header.dataSize = dataSize;
  header.fileSize = dataSize + WAV_HEADER_SIZE - 8;
  
  file.write((uint8_t*)&header, sizeof(WAVHeader));
}

// ===== Button Handler =====
void handleButtons() {
  static unsigned long lastDebounce = 0;
  static const unsigned long debounceDelay = 200;
  
  if (millis() - lastDebounce < debounceDelay) {
    return;
  }
  
  // Start button
  if (digitalRead(BTN_START) == LOW) {
    lastDebounce = millis();
    if (currentState == STATE_IDLE) {
      startRecording();
    }
  }
  
  // Stop button
  if (digitalRead(BTN_STOP) == LOW) {
    lastDebounce = millis();
    if (currentState == STATE_RECORDING) {
      stopRecording();
    } else if (currentState == STATE_PLAYING) {
      stopPlayback();
    }
  }
  
  // Play button
  if (digitalRead(BTN_PLAY) == LOW) {
    lastDebounce = millis();
    if (currentState == STATE_IDLE) {
      startPlayback();
    }
  }
}

// ===== Error Handler =====
void printError(const char* message) {
  Serial.print("ERROR: ");
  Serial.println(message);
  ledBlink(5, 100);
}
